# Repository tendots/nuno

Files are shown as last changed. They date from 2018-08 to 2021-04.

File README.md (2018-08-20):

# nuno
Electric fabric touchsensor module "nüno"

導電布タッチセンサーモジュールnünoのコードです。

質問や要望などあればこのページかFacebookページへご連絡ください。
* Facebook page https://www.facebook.com/Project-n%C3%BCno-183796265747425/

## 仕様 ##
* 静電容量タッチセンサ　[mtch6102](https://www.microchip.com/wwwproducts/en/MTCH6102)
* タッチチャンネル数8
* コネクタ GROVEコネクタ(I2C)

## 導線部接続方法


導線部（細長い方）は画像のように、縫い目がセンサー部（四角い方）の外縁に向くように接続してください。
逆につけた取り付けた場合、すべてのチャンネルの値が取得できません。

## フレキシブル基板コネクタ接続方法 ##


フレキシブル基板のコネクタは、リジット基板のFPCコネクタに接続後、
画像のようにフレキシブル基板と布を両方挟み込むようにして、
付属の固定具でネジ止めしてください。

## 付属ケースカット方法 ##

## 参考 ##
[touch_timer](https://github.com/theapi/touch_timer)

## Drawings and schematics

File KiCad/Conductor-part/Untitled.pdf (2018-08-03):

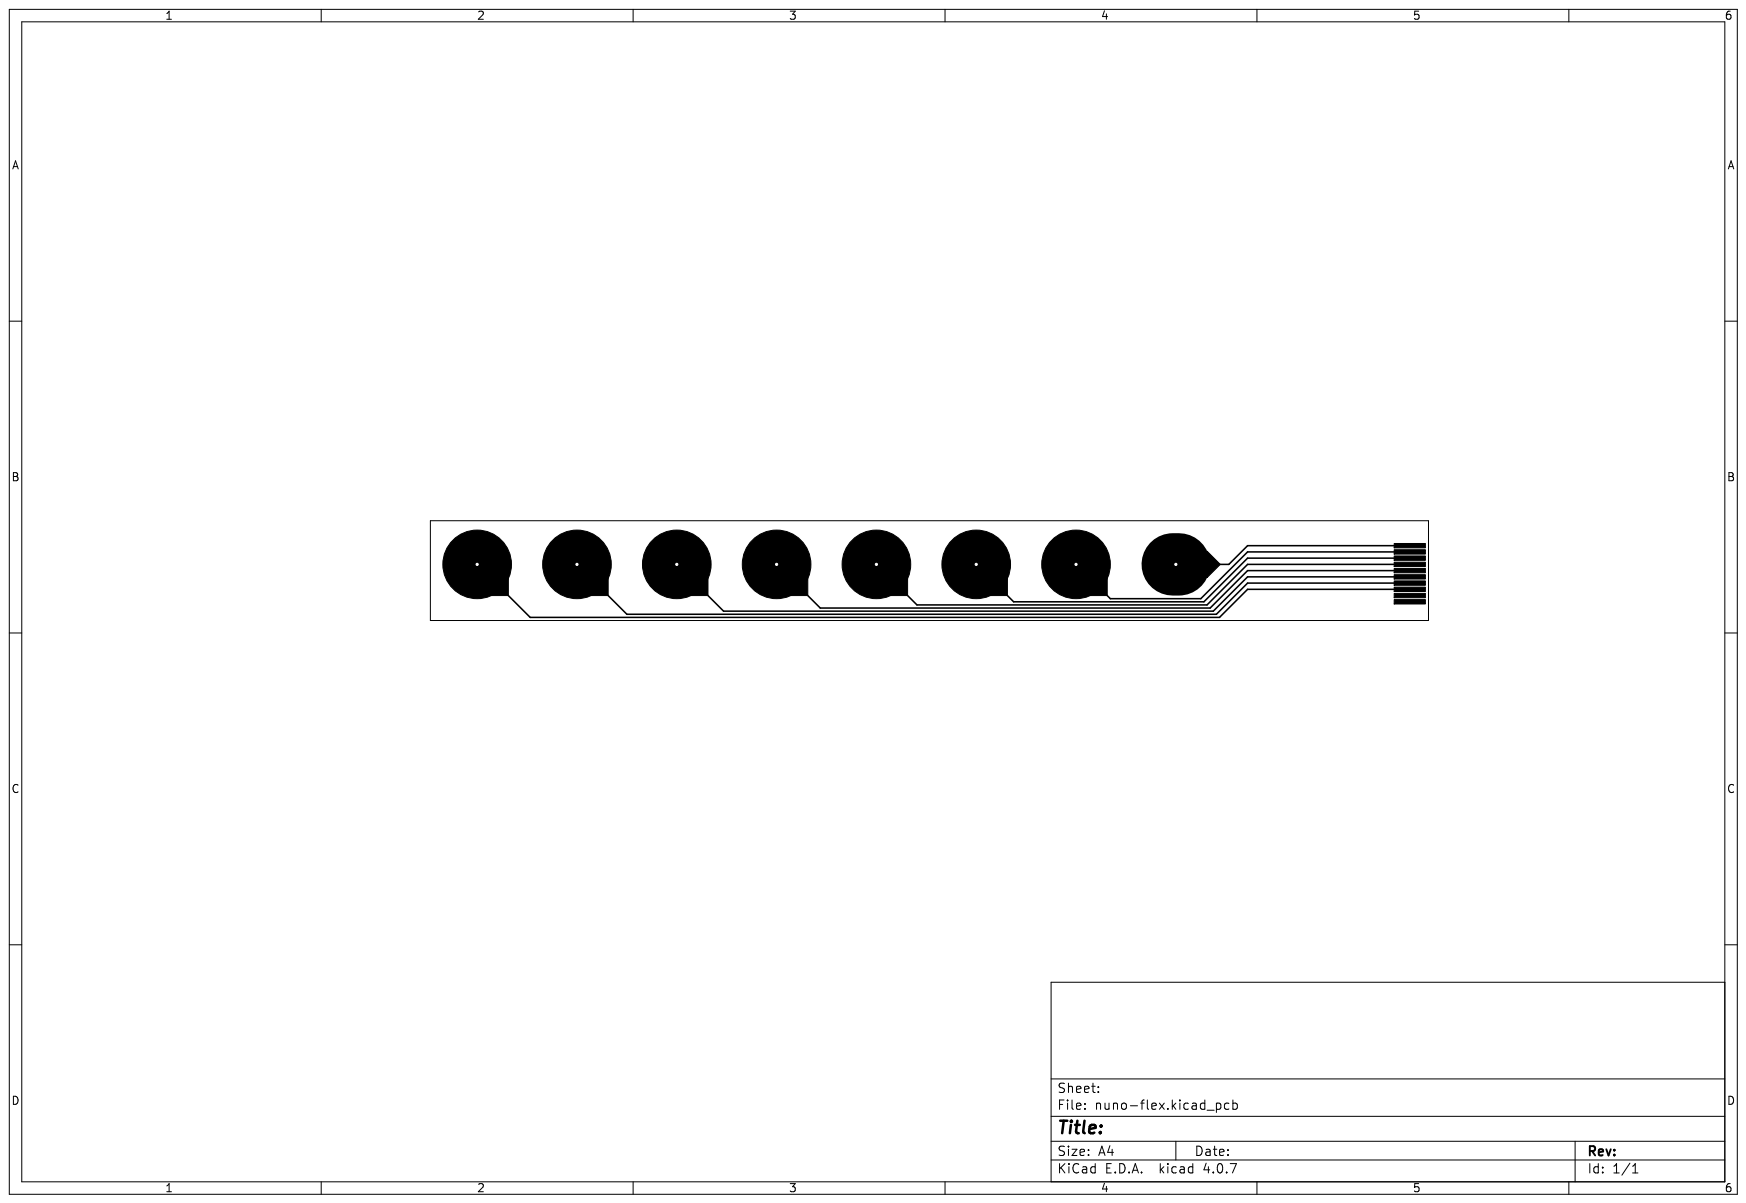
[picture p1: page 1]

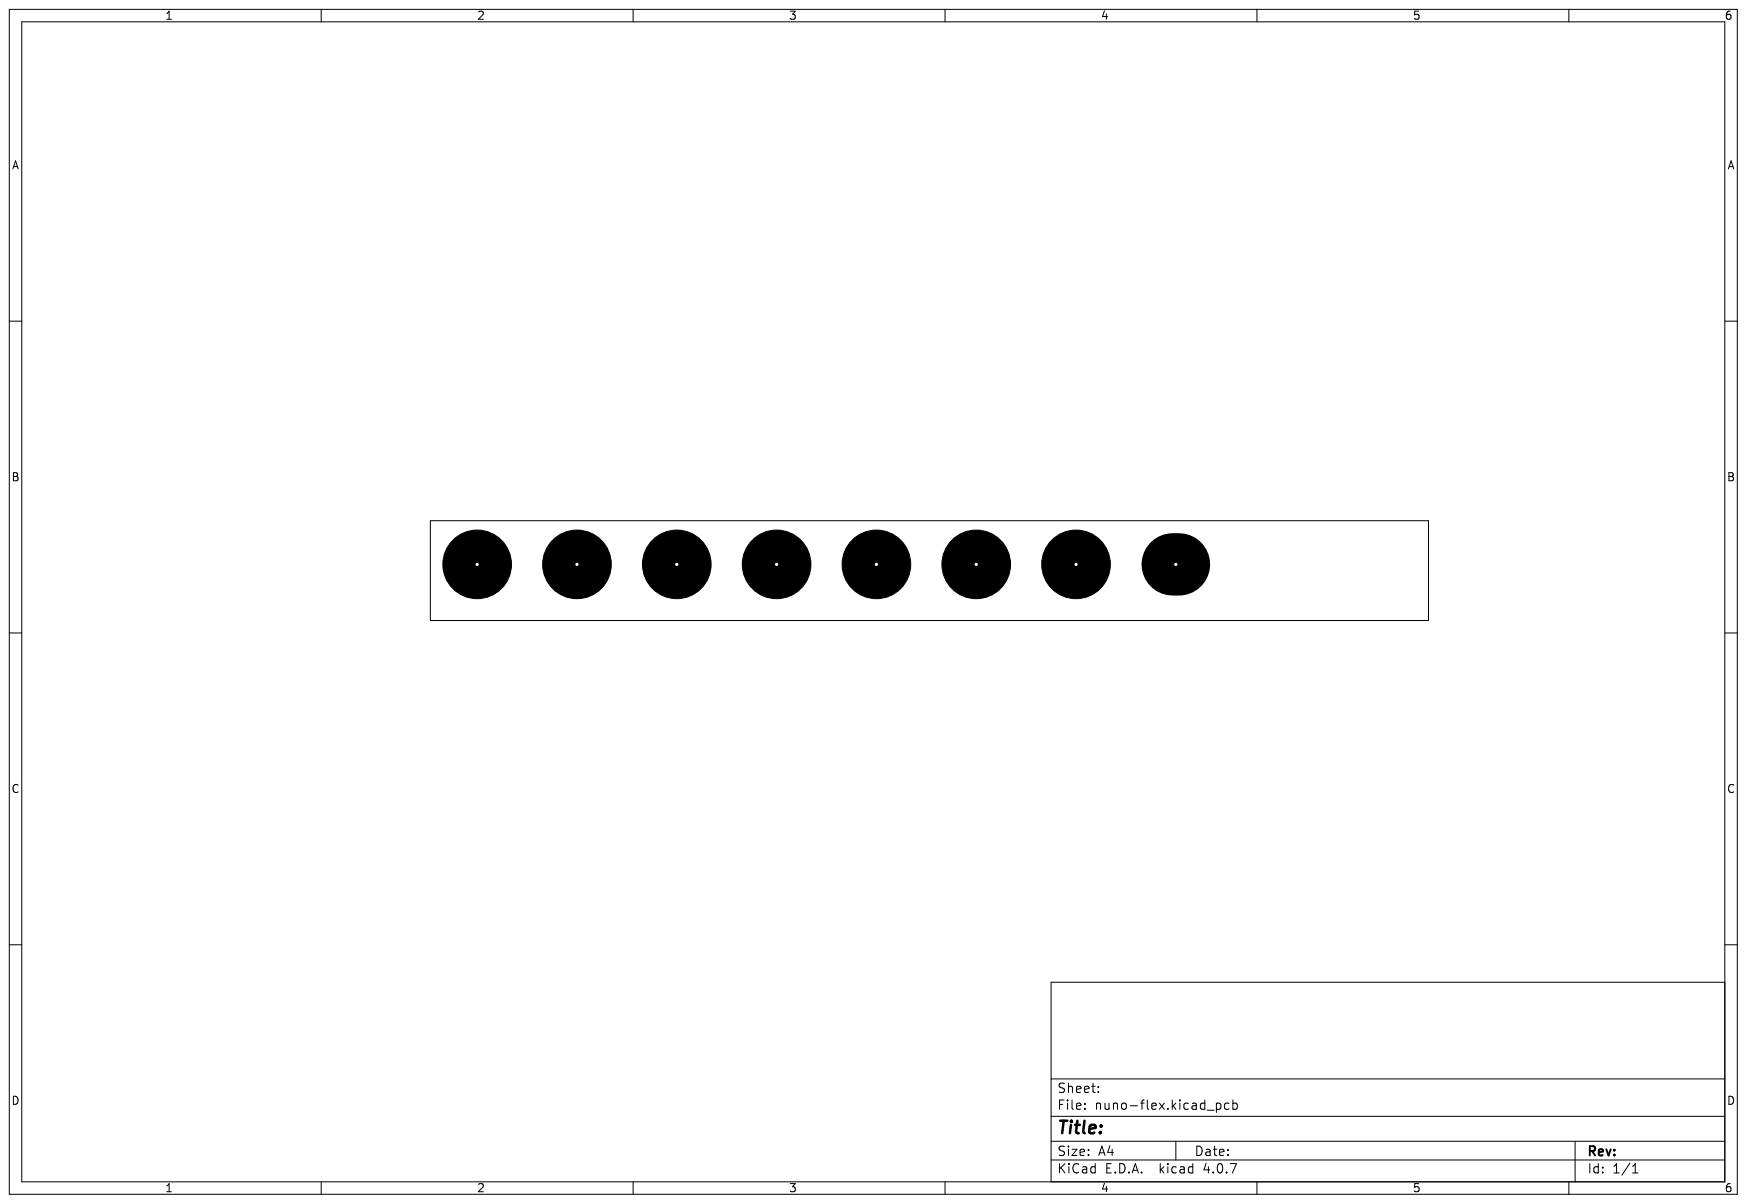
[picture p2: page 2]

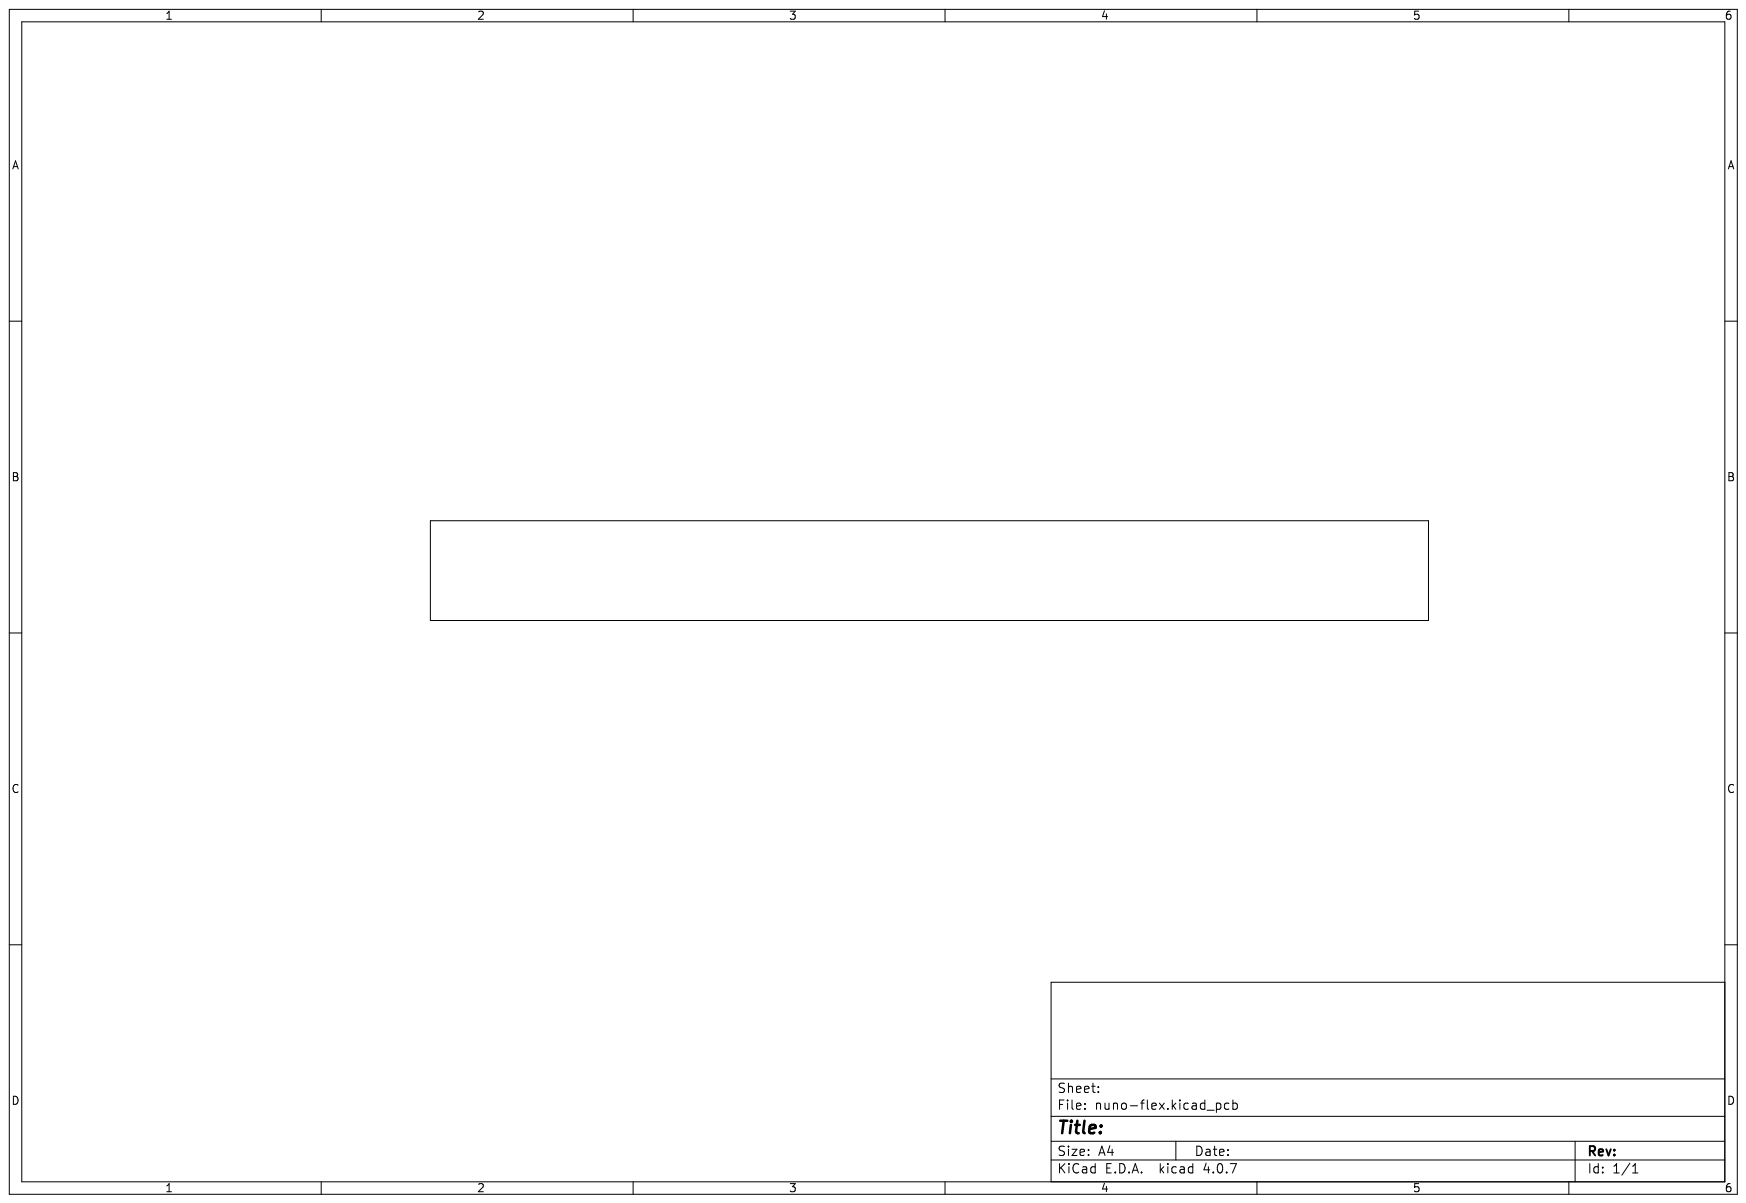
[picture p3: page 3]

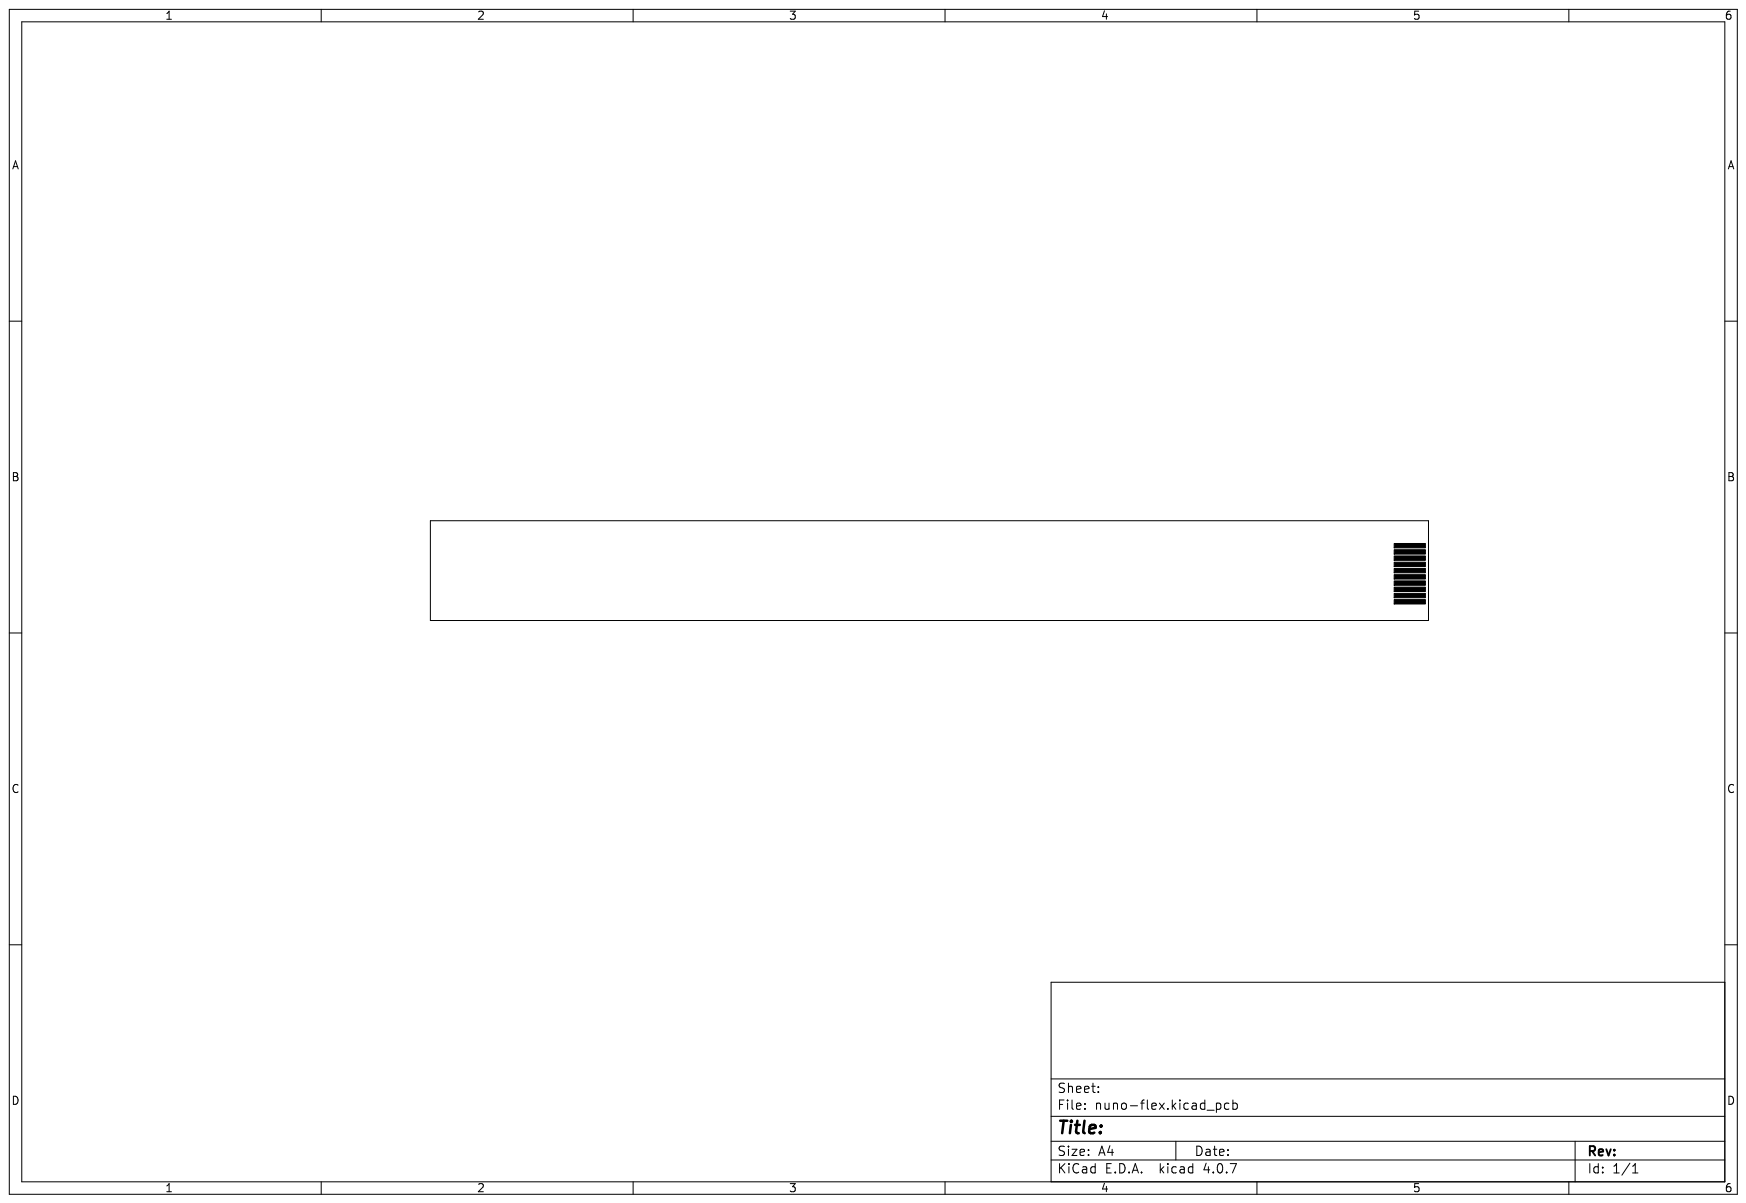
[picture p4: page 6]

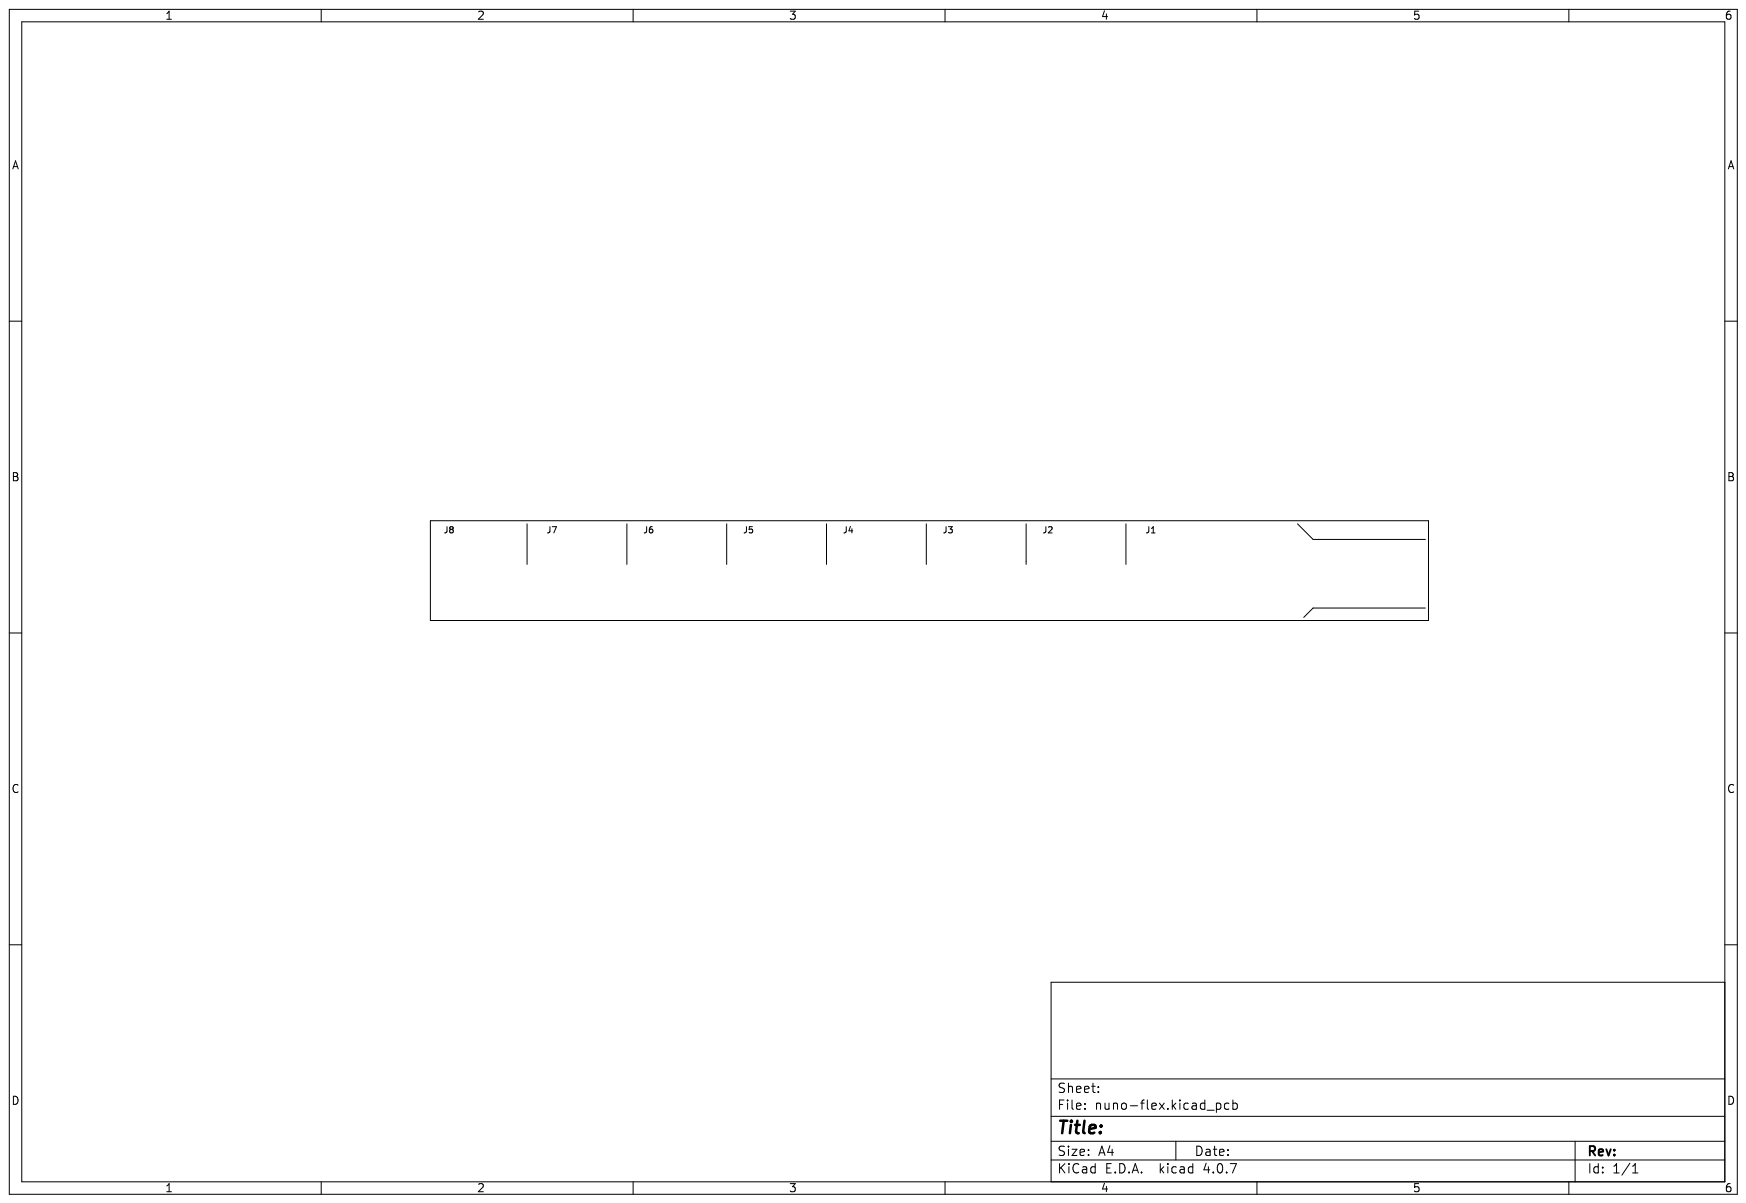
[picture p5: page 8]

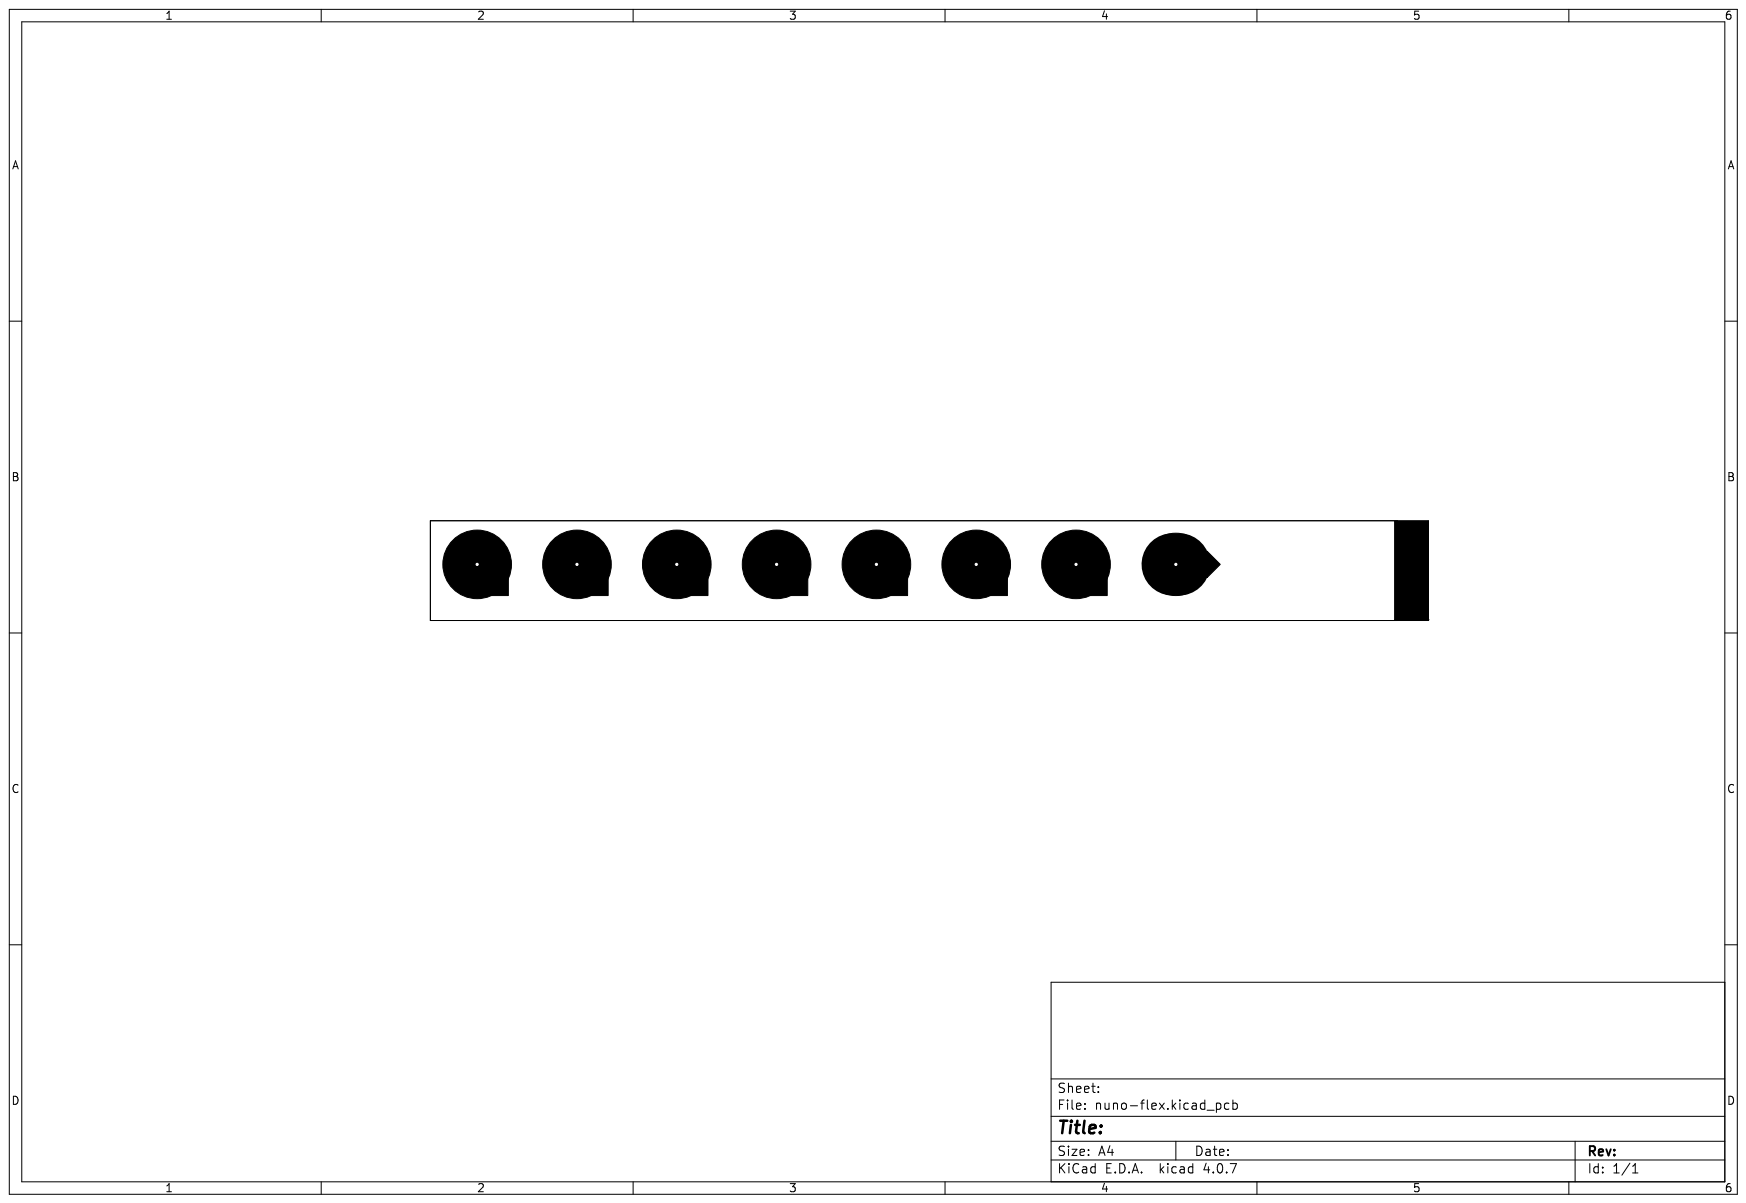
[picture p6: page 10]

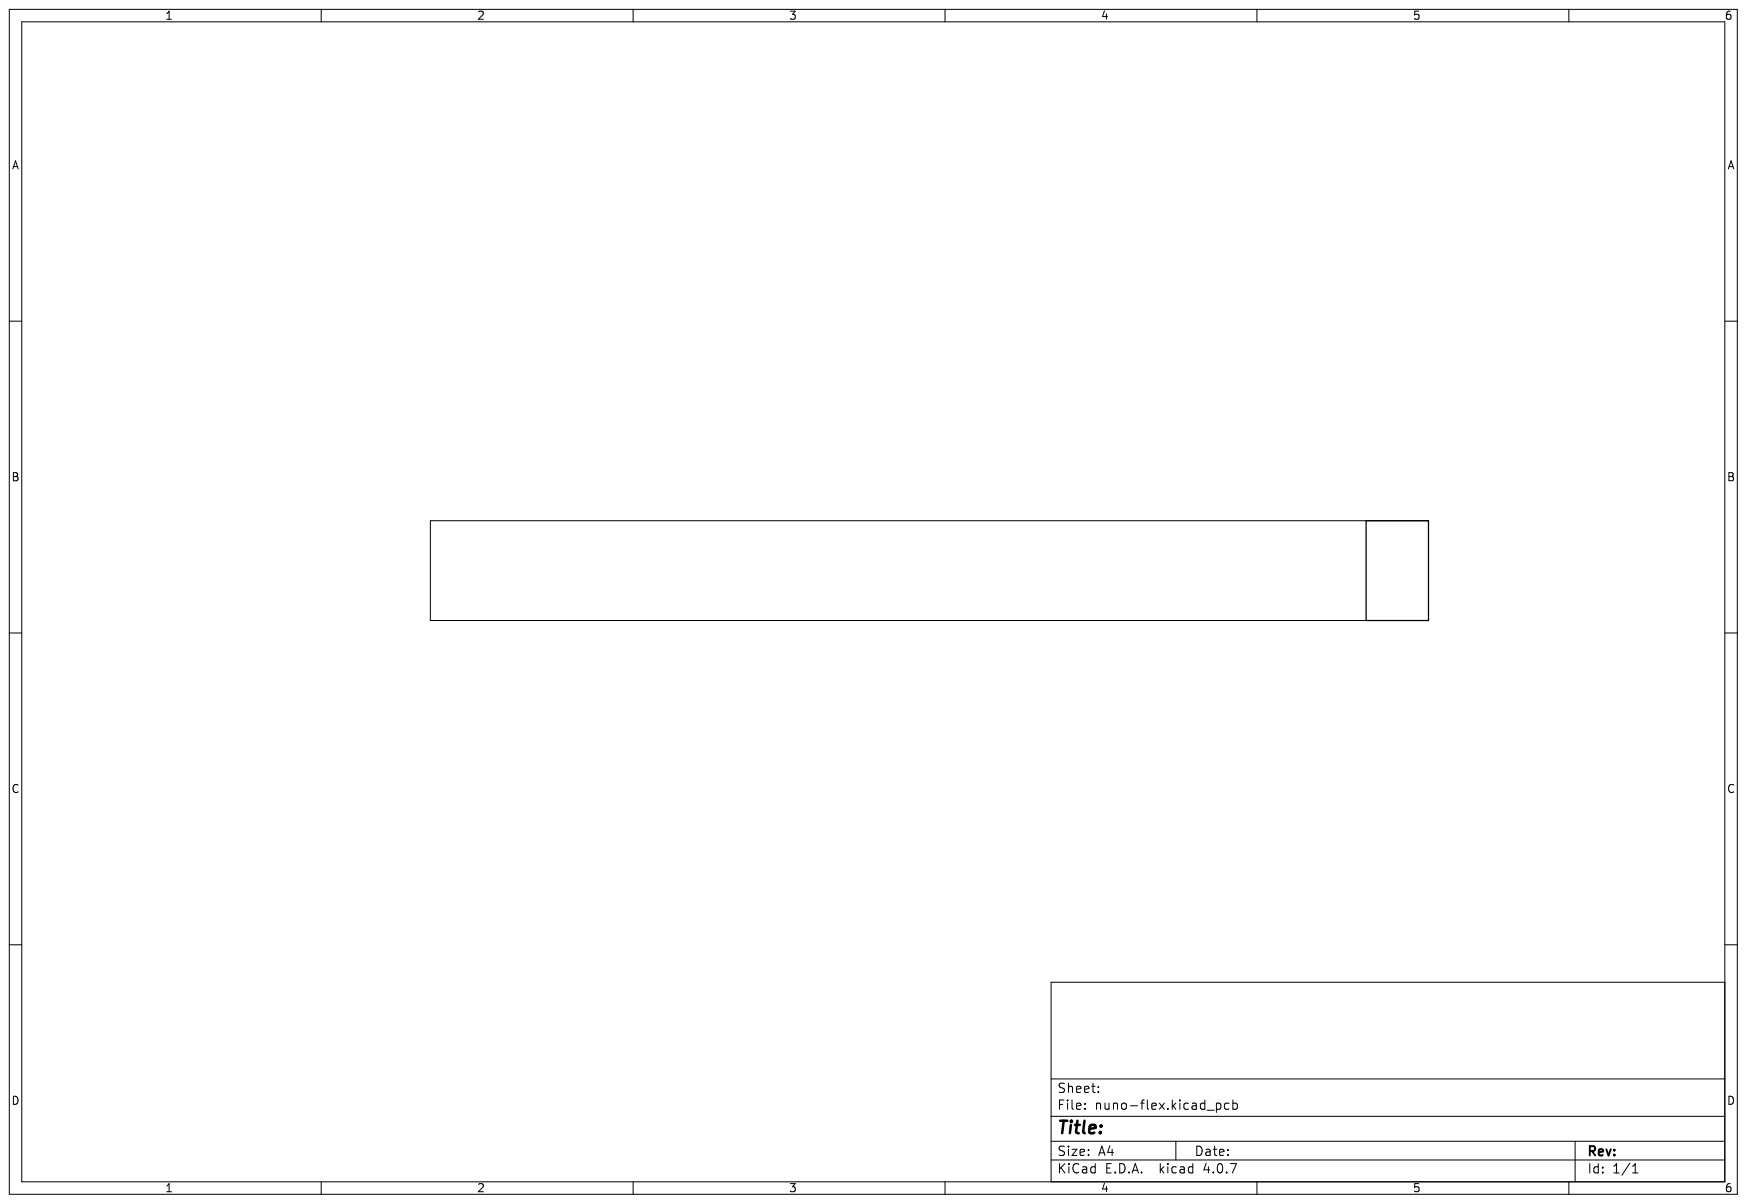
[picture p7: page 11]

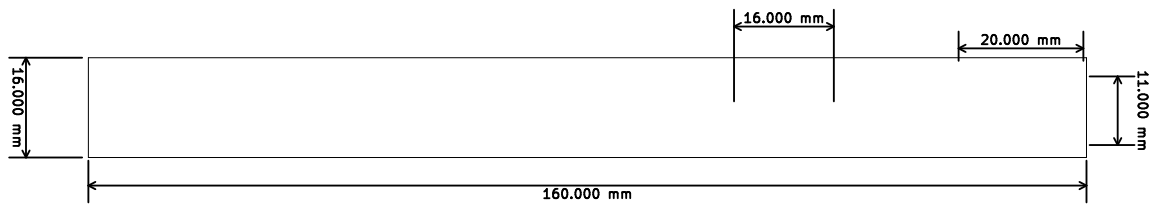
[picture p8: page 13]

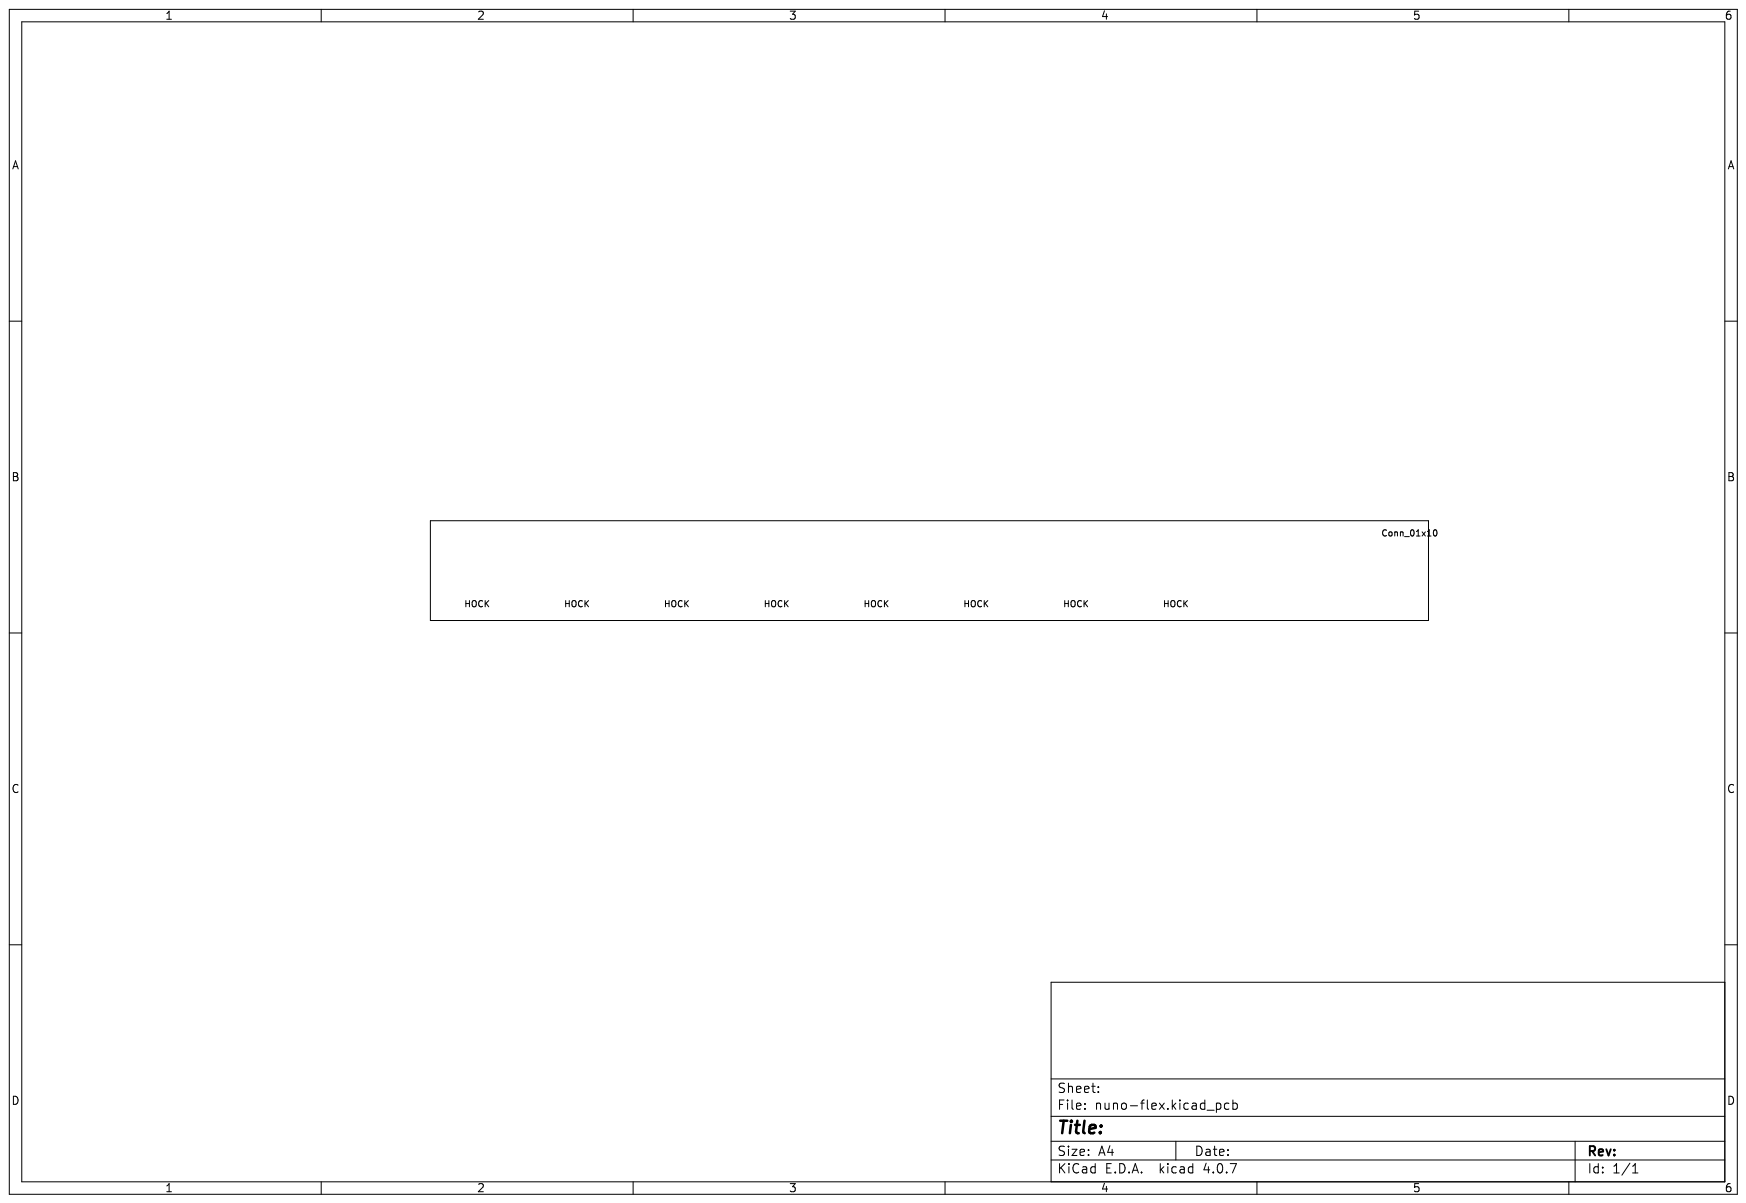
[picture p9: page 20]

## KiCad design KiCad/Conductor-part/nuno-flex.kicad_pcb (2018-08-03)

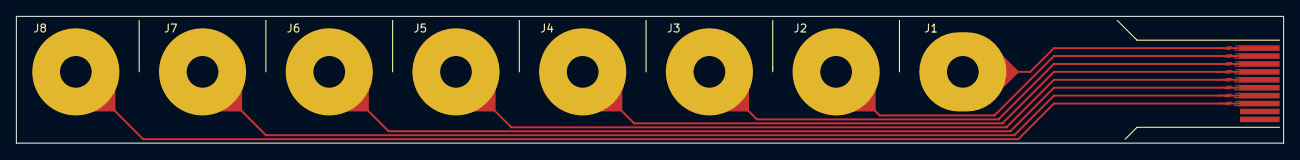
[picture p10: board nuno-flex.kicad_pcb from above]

Board: 2 copper layers, 160.0 x 16.0 mm, 9 parts (0 on the bottom side), 8 nets.

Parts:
J1, J2, J3, J4, J5, J6, J7, J8: HOCK; Hock_4mm
J10: Conn_01x10; FPP_CONN_10

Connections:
unnamed: J1.1, J10.1
unnamed: J2.2, J10.2
unnamed: J3.3, J10.3
unnamed: J4.4, J10.4
unnamed: J5.5, J10.5
unnamed: J6.6, J10.6
unnamed: J7.7, J10.7
unnamed: J8.8, J10.8

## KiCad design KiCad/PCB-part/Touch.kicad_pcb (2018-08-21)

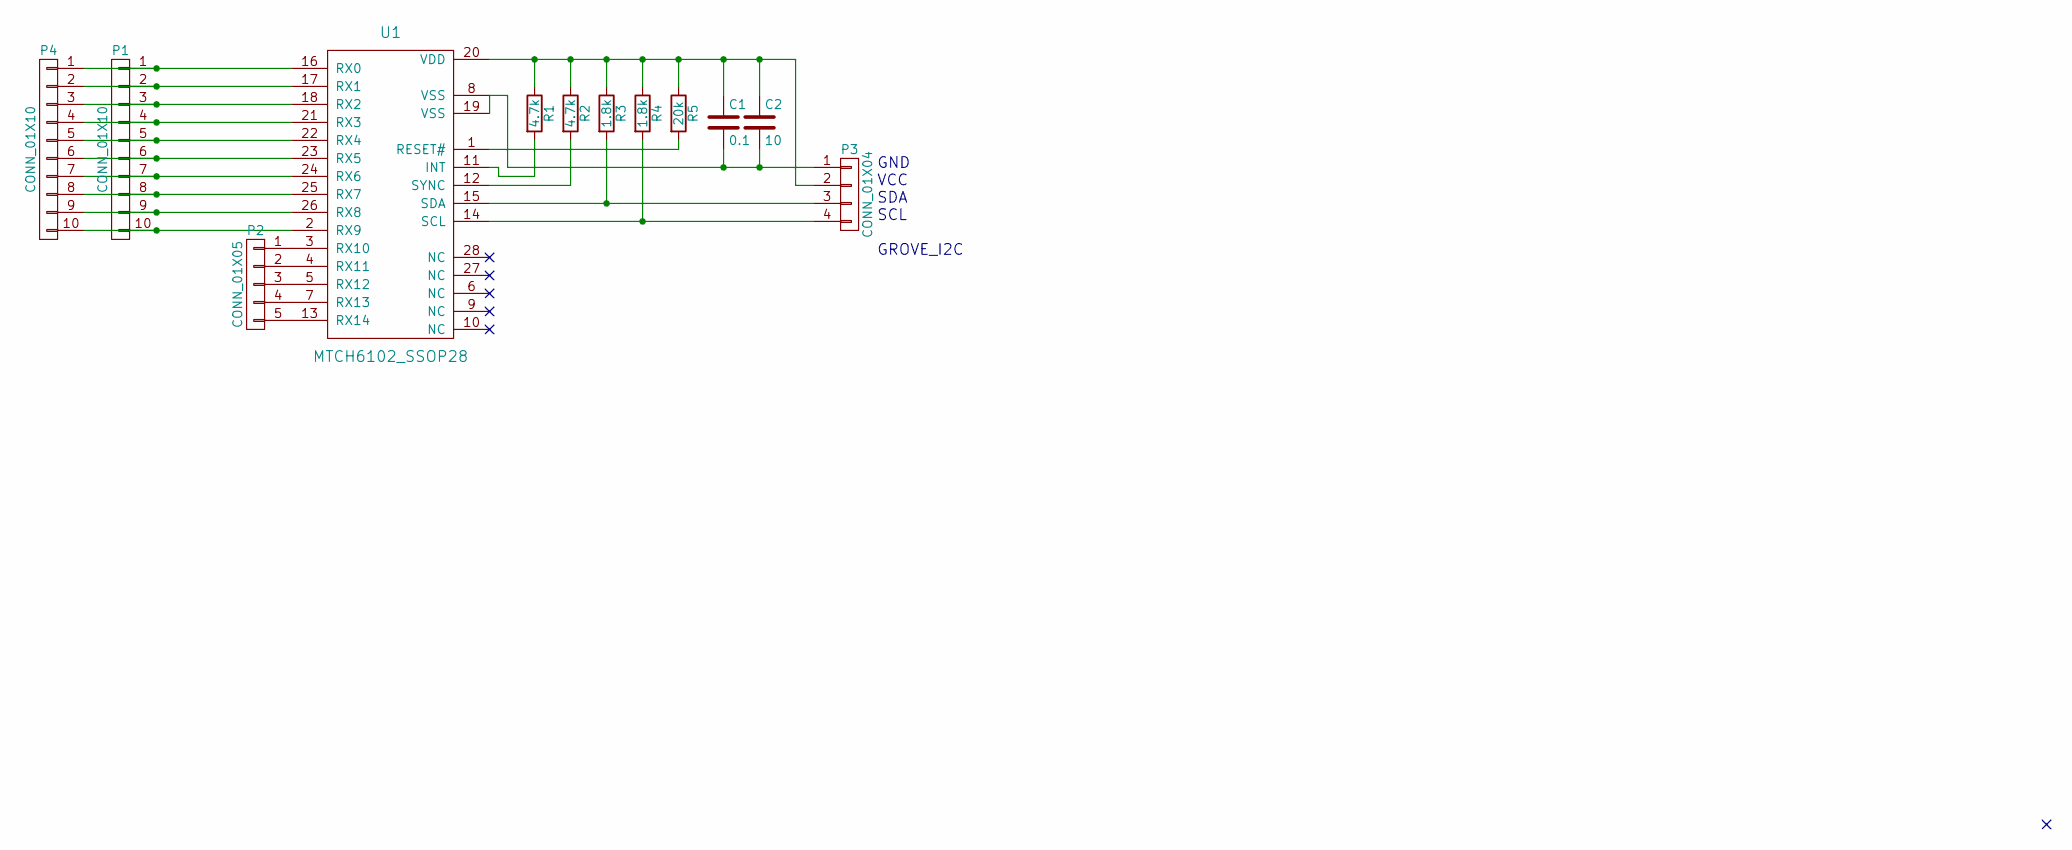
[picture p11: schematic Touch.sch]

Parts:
C1: 0.1; C_0603
C2: 10; C_0603
P1: CONN_01X10; Connector_Molex_PicoBlade_53047-1010
P2: CONN_01X05; Connector_Molex_PicoBlade_53047-0510
P3: CONN_01X04; Grove_I2C_Horisontal_4pin_2mmpitch
P4: CONN_01X10; FFC_CONNECTOR_1.0D-WTS-10P
R1, R2: 4.7k; R_0603
R3, R4: 1.8k; R_0603
R5: 20k; R_0603
U1: MTCH6102_SSOP28; SSOP-28_5.3x10.2mm_Pitch0.65mm

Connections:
unnamed: C1.1, C2.1, P3.2, R1.1, R2.1, R3.1, R4.1, R5.1, U1.20 (VDD)
unnamed: C1.2, C2.2, P3.1, U1.8 (VSS), U1.19 (VSS)
unnamed: P1.1, P4.1, U1.16 (RX0)
unnamed: P1.2, P4.2, U1.17 (RX1)
unnamed: P1.3, P4.3, U1.18 (RX2)
unnamed: P1.4, P4.4, U1.21 (RX3)
unnamed: P1.5, P4.5, U1.22 (RX4)
unnamed: P1.6, P4.6, U1.23 (RX5)
unnamed: P1.7, P4.7, U1.24 (RX6)
unnamed: P1.8, P4.8, U1.25 (RX7)
unnamed: P1.9, P4.9, U1.26 (RX8)
unnamed: P1.10, P4.10, U1.2 (RX9)
unnamed: P2.1, U1.3 (RX10)
unnamed: P2.2, U1.4 (RX11)
unnamed: P2.3, U1.5 (RX12)
unnamed: P2.4, U1.7 (RX13)
unnamed: P2.5, U1.13 (RX14)
unnamed: P3.3, R3.2, U1.15 (SDA)
unnamed: P3.4, R4.2, U1.14 (SCL)
unnamed: R1.2, U1.11 (INT)
unnamed: R2.2, U1.12 (SYNC)
unnamed: R5.2, U1.1 (RESET#)

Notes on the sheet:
GND VCC SDA SCL GROVE_I2C

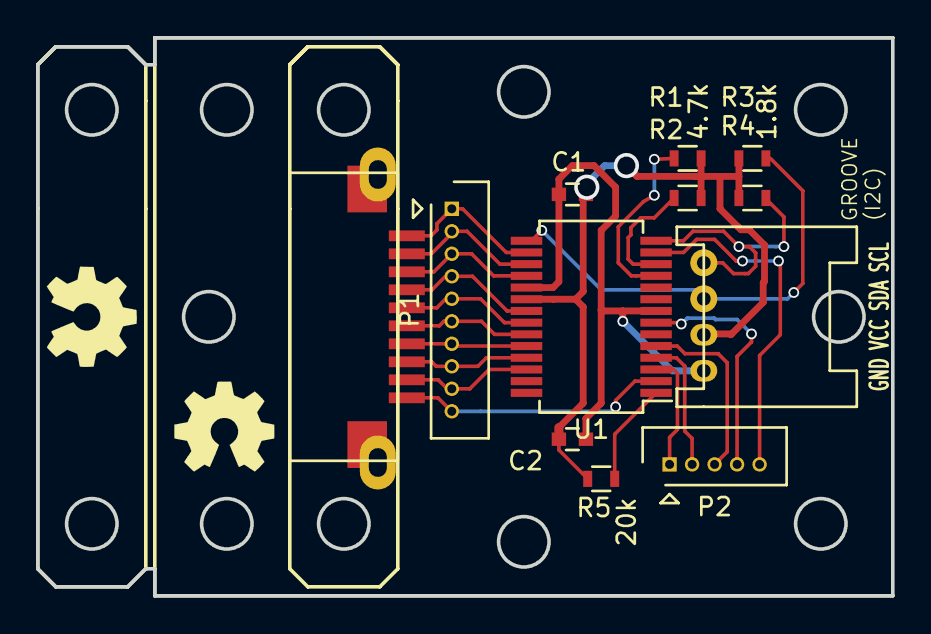
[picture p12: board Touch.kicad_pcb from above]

Board: 2 copper layers, 47.5 x 31.0 mm, 14 parts (0 on the bottom side), 22 nets.

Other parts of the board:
OSHW: 1.1; OSHW_LOGL_SYLK_5mm
OSHW#2: 1.1; OSHW_LOGL_SYLK_5mm

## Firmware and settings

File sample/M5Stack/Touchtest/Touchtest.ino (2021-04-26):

#include <M5Stack.h>
#include "MTCH6102.h"
#define ADDR 0x25
#define ScreenWidth 320
#define ScreenHeight 240

MTCH6102 mtch = MTCH6102();
int len = 8;

void setup() { 

  // Initialize the M5Stack object
  M5.begin();
  //Wire.begin();
  M5.Power.begin();

 
  
  //Serial.begin(115200);
  delay(100);
  Serial.println();
  Serial.println("start");
  
  //Wire.begin();
  mtch.begin();
  mtch.writeRegister(MTCH6102_MODE, MTCH6102_MODE_STANDBY);
  mtch.writeRegister(MTCH6102_NUMBEROFXCHANNELS, 0x08);
  mtch.writeRegister(MTCH6102_NUMBEROFYCHANNELS, 0x03);//最低3点必要なため
  mtch.writeRegister(MTCH6102_MODE, MTCH6102_MODE_FULL);
  
  byte data;

  // the operating mode (MODE)
  data = mtch.readRegister(MTCH6102_MODE);
  Serial.print("MODE: ");
  Serial.println(data,BIN);

  data = mtch.readRegister(MTCH6102_NUMBEROFXCHANNELS);
  Serial.print("NUMBEROFXCHANNELS: ");
  Serial.println(data);

  data = mtch.readRegister(MTCH6102_NUMBEROFYCHANNELS);
  Serial.print("NUMBEROFYCHANNELS: ");
  Serial.println(data);
  
  mtch.writeRegister(MTCH6102_CMD, 0x20);
  delay(500);

  
}

void loop() {
  M5.Lcd.setCursor(0, 70);
  
  byte data; 
  float sensVals[10]={0,0,0,0,0,0,0,0,0,0};

  //背景ライン
  for(int i=0; i<len; i++){
    M5.Lcd.drawLine((i+1)*35, ScreenHeight-40, (i+1)*35, 0, 0x0000cc);
  }
  for(int i=1; i<11; i++){
    M5.Lcd.drawLine(0, i*20, ScreenWidth, i*20, 0x0000cc);
  }

  Serial.print("SENSORVALUE_RX <i>: ");
  //for (byte i = MTCH6102_SENSORVALUE_RX0; i < MTCH6102_SENSORVALUE_RX0+10; i++) {
  for (int i = 0; i < len; i++) {
     data = mtch.readRegister(MTCH6102_SENSORVALUE_RX0+(i+2));
     
    Serial.print(data);
    Serial.print(", ");

    sensVals[i] = data;

    M5.Lcd.fillRect(30+(i*35), ScreenHeight-20, 30, 10, TFT_BLACK);
    M5.Lcd.setCursor(30+(i*35), ScreenHeight-20);
    M5.Lcd.print(data);
  }

  //グラフ線の描画
  int leftMargin = 0;
  for (int i = 0; i<len+1; i++){
    float prev;
    float current;
    if(i==0){
       prev = 0;
    }if(i==len+1){
      current = 0;
    }else{
       prev=sensVals[i-1];
       current = sensVals[i];
    }
    
    M5.Lcd.drawLine(leftMargin+(i*35), 200-(prev/255)*200, leftMargin+((i+1)*35), 200-(current/255)*200, TFT_WHITE);
  }
  delay(50);
  

  
  //グラフ線の消去
  for (int i = 0; i<len+1; i++){
    float prev;
    float current;
    if(i==0){
       prev = 0;
    }if(i==len+1){
      current = 0;
    }else{
       prev=sensVals[i-1];
       current = sensVals[i];
    }
    M5.Lcd.drawLine(leftMargin+(i*35), 200-(prev/255)*200, leftMargin+((i+1)*35), 200-(current/255)*200, TFT_BLACK);
  }
   
  Serial.println();
  M5.Lcd.println();
  M5.update();
  
 }

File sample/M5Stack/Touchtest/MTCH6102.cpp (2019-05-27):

#include "MTCH6102.h"

MTCH6102::MTCH6102() {}

boolean MTCH6102::begin(uint8_t i2caddr) {
  Wire.begin();

  _i2caddr = i2caddr;

  return true;
}

uint8_t MTCH6102::readRegister(uint8_t reg) {
  byte error;
  Wire.beginTransmission(_i2caddr);
  Wire.write(reg); // register to read
  //Wire.endTransmission(false);
  error = Wire.endTransmission();
  // read a byte
  while (Wire.requestFrom(_i2caddr, 1) != 1);
  return ( Wire.read());
}

void MTCH6102::writeRegister(uint8_t reg, uint8_t value) {
  Wire.beginTransmission(_i2caddr);
  Wire.write((uint8_t)reg); // register to read
  Wire.write((uint8_t)(value));
  Wire.endTransmission();
}

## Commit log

2018-08-03 M5Stack用サンプル
2018-08-03 KiCadファイルを追加
    [nuno-flex.kicad_pcb, nuno-flex.sch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]
2018-08-03 仕様書を追加
2018-08-06 Update README.md
    導線部接続方法とフレキシブル基板コネクタ接続方法を追記
2018-08-21 Add PCB KiCad files
    [Touch-B.Cu.gbr, Touch-B.Mask.gbr, Touch-B.SilkS.gbr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]
2018-09-07 仕様書aiファイルを削除
2018-10-08 MTCH6102.cppの反応を改善
2019-05-27 readRegisterがうまく動かないのを修正 リファクタリング実行
2021-04-26 nuno v2をM5Stack Core向けに修正
